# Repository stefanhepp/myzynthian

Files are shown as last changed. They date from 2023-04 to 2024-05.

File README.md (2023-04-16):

README
------

This project is a Zynthian case build with the following features:

- The hardware is based on:
    - Raspberry Pi 3/4 with passive cooler
    - IQaudio DAC+ audio shield
    - 7" LCD DSI Touchscreen
- Custom IO expander board for MIDI, 4x encoders

Sources
-------

The IO Expander board design is based on Zynthian's Zynaptic v3 design:
https://github.com/zynthian/zynthian-hw

The FreeCAD design uses the following models:
- 7" Display Reference Model: From Printables User Clough42: 
  https://www.printables.com/model/202234-official-raspberry-pi-7-touch-screen-reference-mod
- Raspberry PI 4: From GrabCAD User Zahid Salman: https://grabcad.com/library/raspberry-pi-model-3-4-cooling-1
- HifiBerry: From GrabCAD User Alain Gourvès: https://grabcad.com/library/hifiberry-dac-1
- Rotary Encoder: From GrabCAD User joel bennett: https://grabcad.com/library/rotary-encoder-ky-040-2
- DIN 5F Socket: From GrabCAD User Leininger Stéphane: https://grabcad.com/library/din-5f-type-mab-1
- LED 3mm: From GrabCAD User John Walker: https://grabcad.com/library/led-3mm-with-housing-1 

License
-------
Shield: [][cc-by-sa]

This work is licensed under a
[Creative Commons Attribution-ShareAlike 4.0 International License][cc-by-sa].

[][cc-by-sa]

[cc-by-sa]: http://creativecommons.org/licenses/by-sa/4.0/
[cc-by-sa-image]: https://licensebuttons.net/l/by-sa/4.0/88x31.png
[cc-by-sa-shield]: https://img.shields.io/badge/License-CC%20BY--SA%204.0-lightgrey.svg

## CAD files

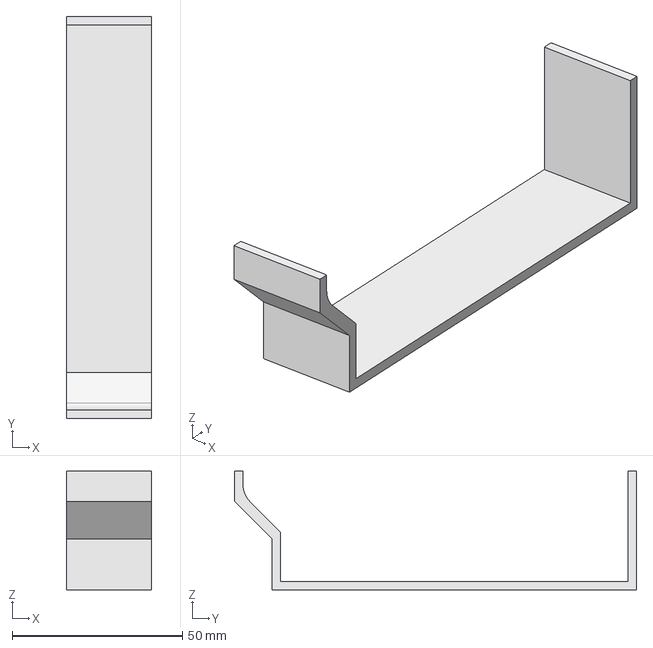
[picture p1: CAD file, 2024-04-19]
case/MyZynthian-Boutique-AssemblyHelper.step
25.0 x 118.0 x 34.9 mm

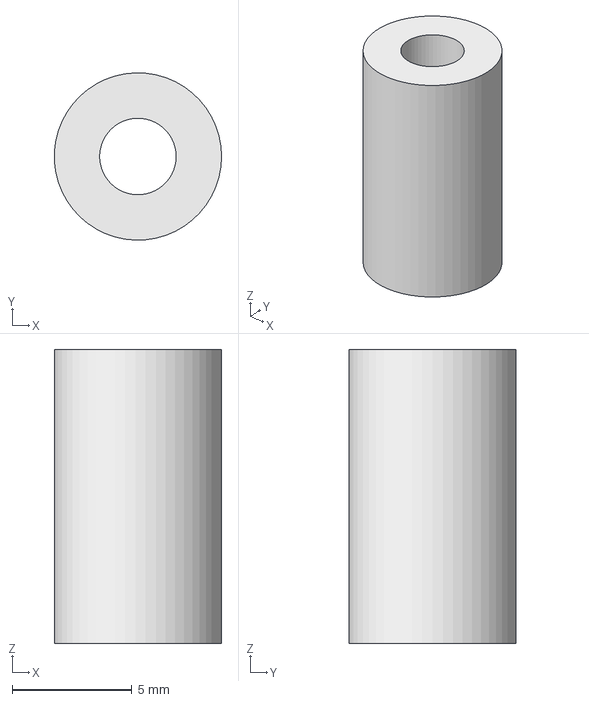
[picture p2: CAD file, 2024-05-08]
case/PCB-Spacer.FCStd
6.99 x 7.00 x 12.3 mm

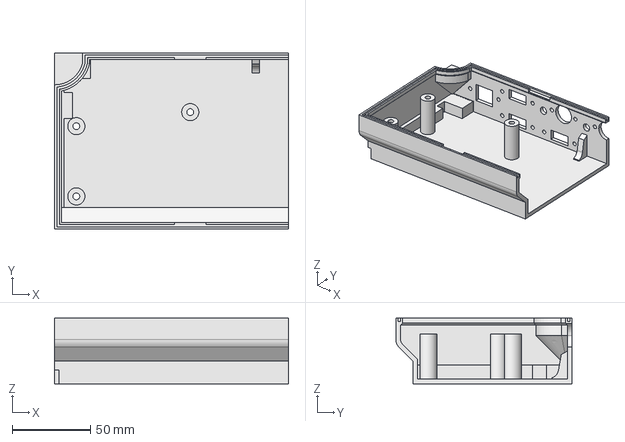
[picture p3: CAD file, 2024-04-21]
case/MyZynthian-Boutique-BottomLeft Body.step
150.0 x 113.0 x 42.0 mm

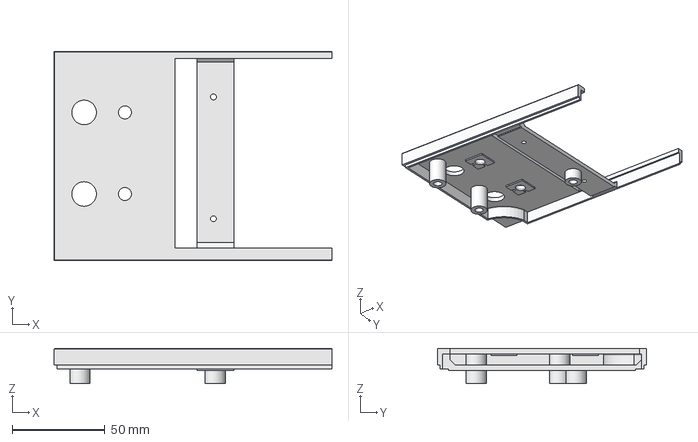
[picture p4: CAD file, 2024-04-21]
case/MyZynthian-Boutique-TopLeft Cover Body.step
149.9 x 113.0 x 19.0 mm

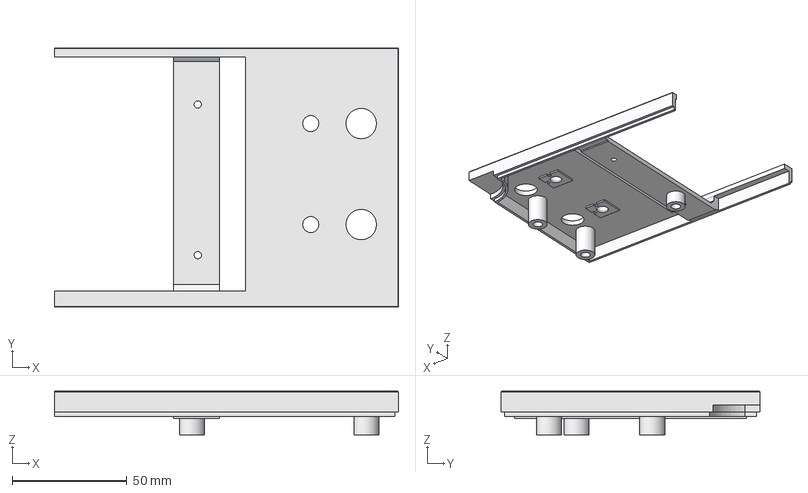
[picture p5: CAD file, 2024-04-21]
case/MyZynthian-Boutique-TopRight Cover Body.step
150.0 x 113.0 x 19.0 mm

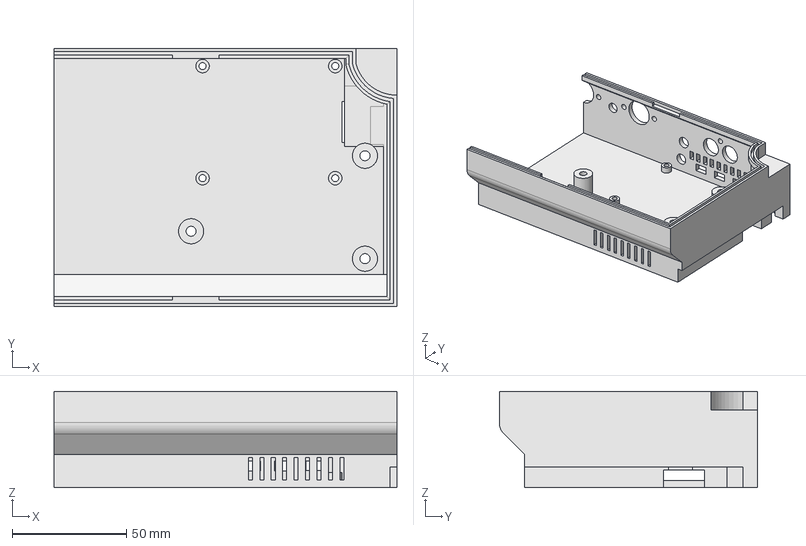
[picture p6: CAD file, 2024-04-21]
case/MyZynthian-Boutique-BottomRight Body.step
150.0 x 113.0 x 42.0 mm

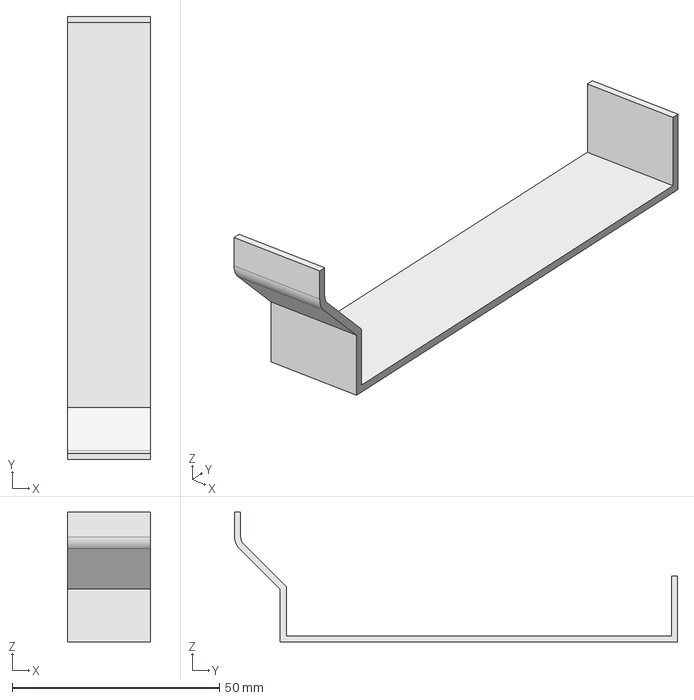
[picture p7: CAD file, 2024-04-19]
case/MyZynthian-Boutique-BodyConnector.step
20.0 x 107.0 x 31.4 mm

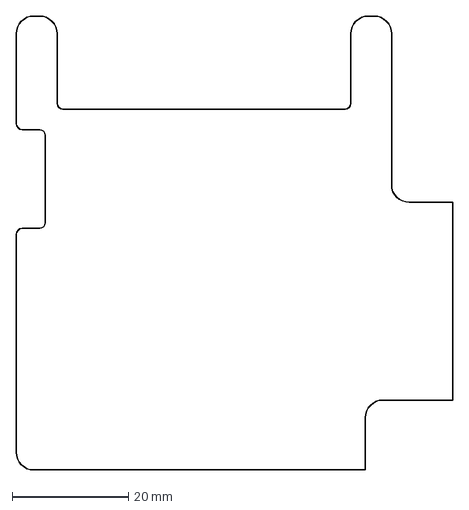
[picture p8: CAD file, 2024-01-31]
case/MyZynthian-Boutique-ZynthianIO Board Outline.dxf
75.0 x 78.0 mm

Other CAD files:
case/PCB-Spacer-Spacer.step

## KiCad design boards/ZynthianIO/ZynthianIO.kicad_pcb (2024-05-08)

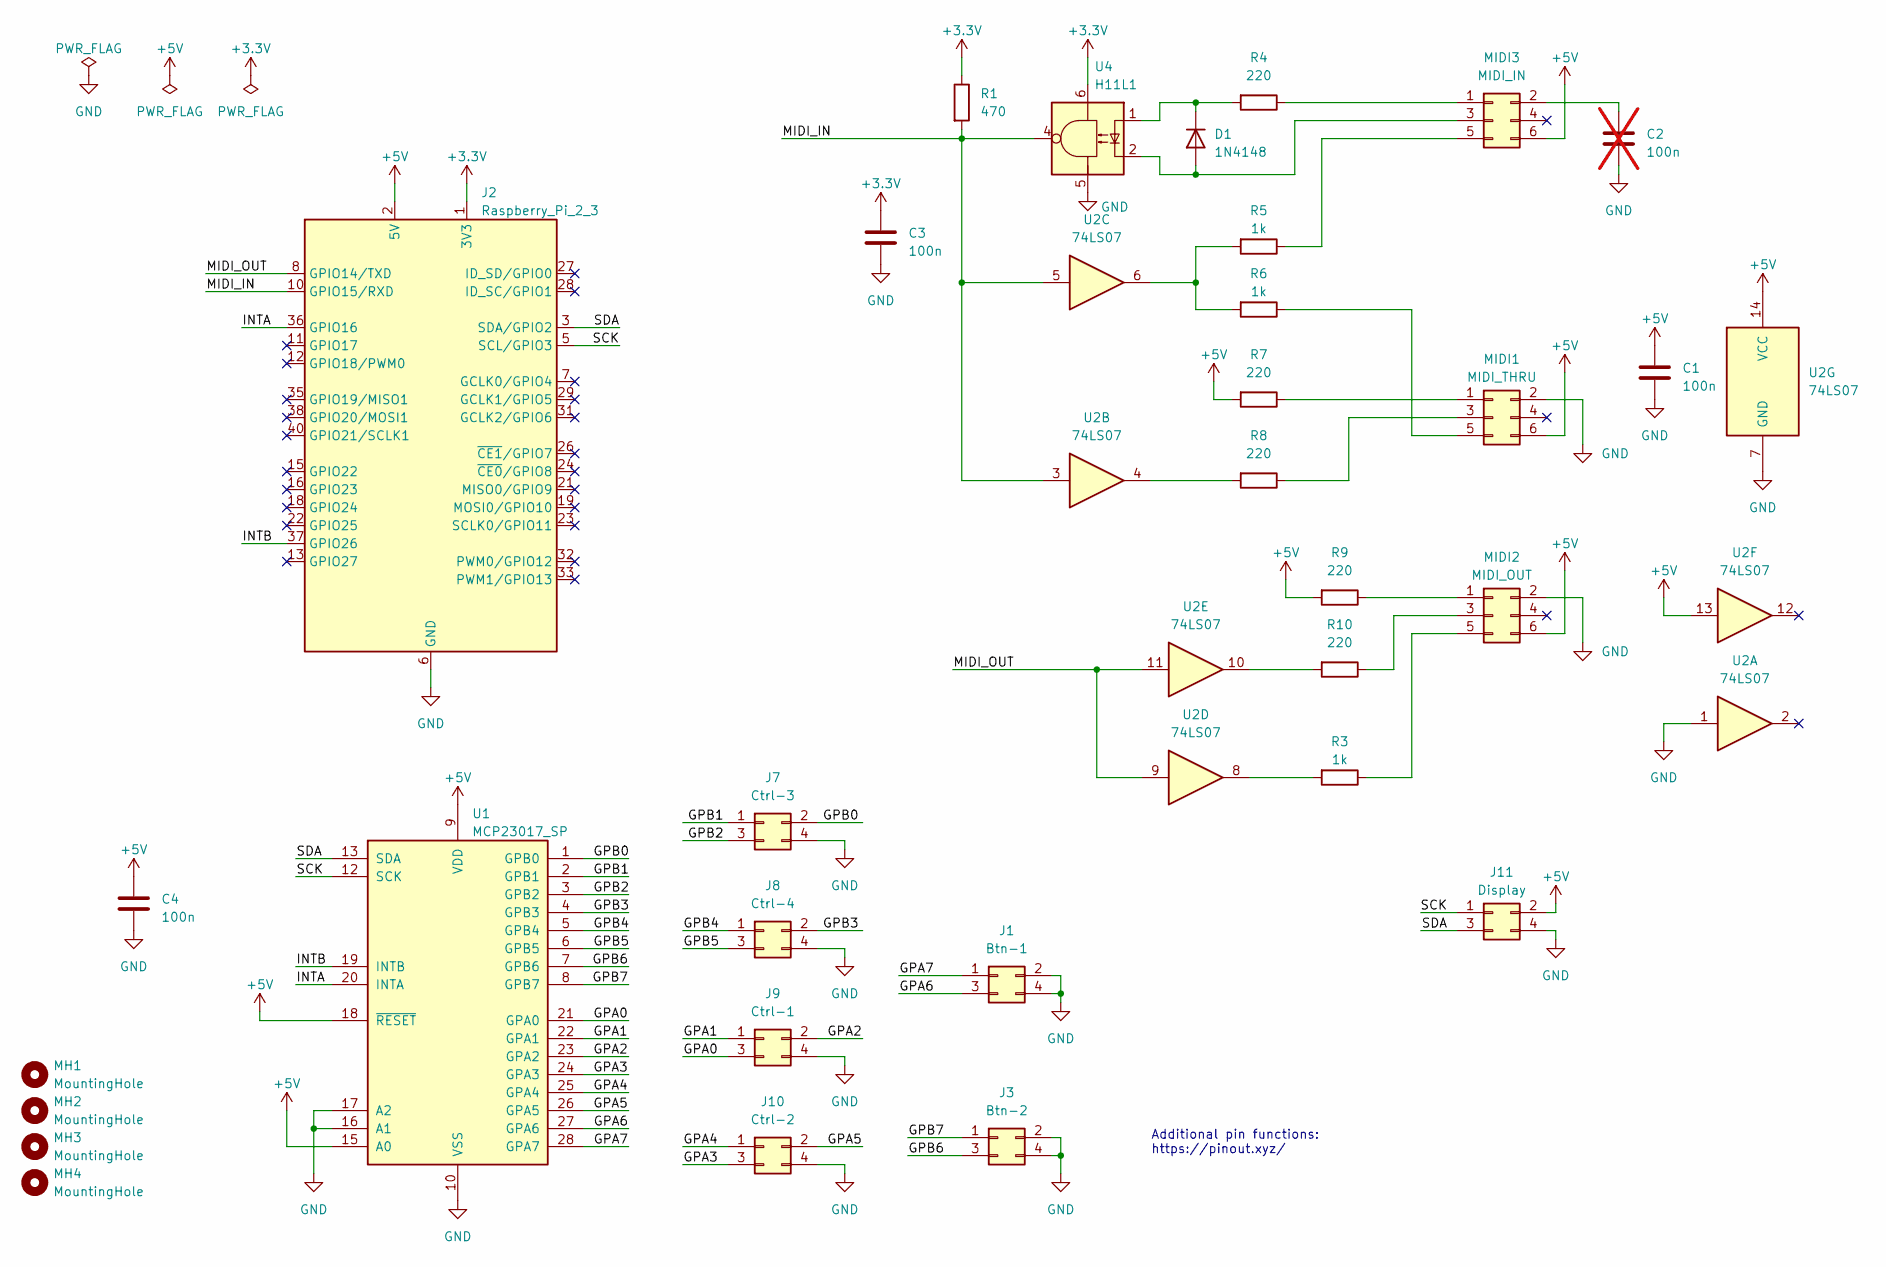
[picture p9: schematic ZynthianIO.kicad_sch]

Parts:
C1, C3, C4: 100n; C_Disc_D5.0mm_W2.5mm_P5.00mm
C2: 100n; C_Disc_D5.0mm_W2.5mm_P5.00mm; not fitted
D1: 1N4148; D_DO-35_SOD27_P7.62mm_Horizontal
J1: Btn-1; PinHeader_2x02_P2.54mm_Horizontal
J2: Raspberry_Pi_2_3; PinSocket_2x20_P2.54mm_Vertical
J3: Btn-2; PinHeader_2x02_P2.54mm_Horizontal
J7: Ctrl-3; PinHeader_2x02_P2.54mm_Horizontal
J8: Ctrl-4; PinHeader_2x02_P2.54mm_Horizontal
J9: Ctrl-1; PinHeader_2x02_P2.54mm_Horizontal
J10: Ctrl-2; PinHeader_2x02_P2.54mm_Horizontal
J11: Display; PinHeader_2x02_P2.54mm_Horizontal
MH1, MH2, MH3, MH4: MountingHole; MountingHole_2.7mm_M2.5
MIDI1: MIDI_THRU; PinHeader_2x03_P2.54mm_Horizontal
MIDI2: MIDI_OUT; PinHeader_2x03_P2.54mm_Horizontal
MIDI3: MIDI_IN; PinHeader_2x03_P2.54mm_Horizontal
R1: 470; R_Axial_DIN0207_L6.3mm_D2.5mm_P10.16mm_Horizontal
R3, R5, R6: 1k; R_Axial_DIN0207_L6.3mm_D2.5mm_P10.16mm_Horizontal
R4, R7, R8, R9, R10: 220; R_Axial_DIN0207_L6.3mm_D2.5mm_P10.16mm_Horizontal
U1: MCP23017_SP; DIP-28_W7.62mm
U2: 74LS07; DIP-14_W7.62mm
U4: H11L1; DIP-6_W7.62mm

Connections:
+3.3V: C3.1, J2.1 (3V3), J2.17 (3V3), R1.1, U4.6
+5V: C1.1, C4.1, J2.2 (5V), J2.4 (5V), J11.2, MIDI1.6, MIDI2.6, MIDI3.6, R7.2, R9.2, U1.9 (VDD), U1.15 (A0), U1.18 (~RESET), U2.13, U2.14 (VCC)
/GPA0: J9.3, U1.21 (GPA0)
/GPA1: J9.1, U1.22 (GPA1)
/GPA2: J9.2, U1.23 (GPA2)
/GPA3: J10.3, U1.24 (GPA3)
/GPA4: J10.1, U1.25 (GPA4)
/GPA5: J10.2, U1.26 (GPA5)
/GPA6: J1.3, U1.27 (GPA6)
/GPA7: J1.1, U1.28 (GPA7)
/GPB0: J7.2, U1.1 (GPB0)
/GPB1: J7.1, U1.2 (GPB1)
/GPB2: J7.3, U1.3 (GPB2)
/GPB3: J8.2, U1.4 (GPB3)
/GPB4: J8.1, U1.5 (GPB4)
/GPB5: J8.3, U1.6 (GPB5)
/GPB6: J3.3, U1.7 (GPB6)
/GPB7: J3.1, U1.8 (GPB7)
/INTA: J2.36 (GPIO16), U1.20 (INTA)
/INTB: J2.37 (GPIO26), U1.19 (INTB)
/MIDI_IN: J2.10 (GPIO15/RXD), R1.2, U2.3, U2.5, U4.4
/MIDI_OUT: J2.8 (GPIO14/TXD), U2.9, U2.11
/SCK: J2.5 (SCL/GPIO3), J11.1, U1.12 (SCK)
/SDA: J2.3 (SDA/GPIO2), J11.3, U1.13 (SDA)
GND: C1.2, C2.2, C3.2, C4.2, J1.2, J1.4, J2.6 (GND), J2.9 (GND), J2.14 (GND), J2.20 (GND), J2.25 (GND), J2.30 (GND), J2.34 (GND), J2.39 (GND), J3.2, J3.4, J7.4, J8.4, J9.4, J10.4, J11.4, MIDI1.2, MIDI2.2, U1.10 (VSS), U1.16 (A1), U1.17 (A2), U2.1, U2.7 (GND), U4.5
unnamed: D1.2 (A), MIDI3.3, U4.2
unnamed: D1.1 (K), R4.2, U4.1
unnamed: MIDI1.1, R7.1
unnamed: MIDI1.3, R8.1
unnamed: MIDI1.5, R6.1
unnamed: MIDI2.1, R9.1
unnamed: MIDI2.3, R10.1
unnamed: MIDI2.5, R3.1
unnamed: MIDI3.1, R4.1
unnamed: C2.1, MIDI3.2
unnamed: MIDI3.5, R5.1
unnamed: R3.2, U2.8
unnamed: R5.2, R6.2, U2.6
unnamed: R8.2, U2.4
unnamed: R10.2, U2.10

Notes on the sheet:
Additional pin functions: https://pinout.xyz/

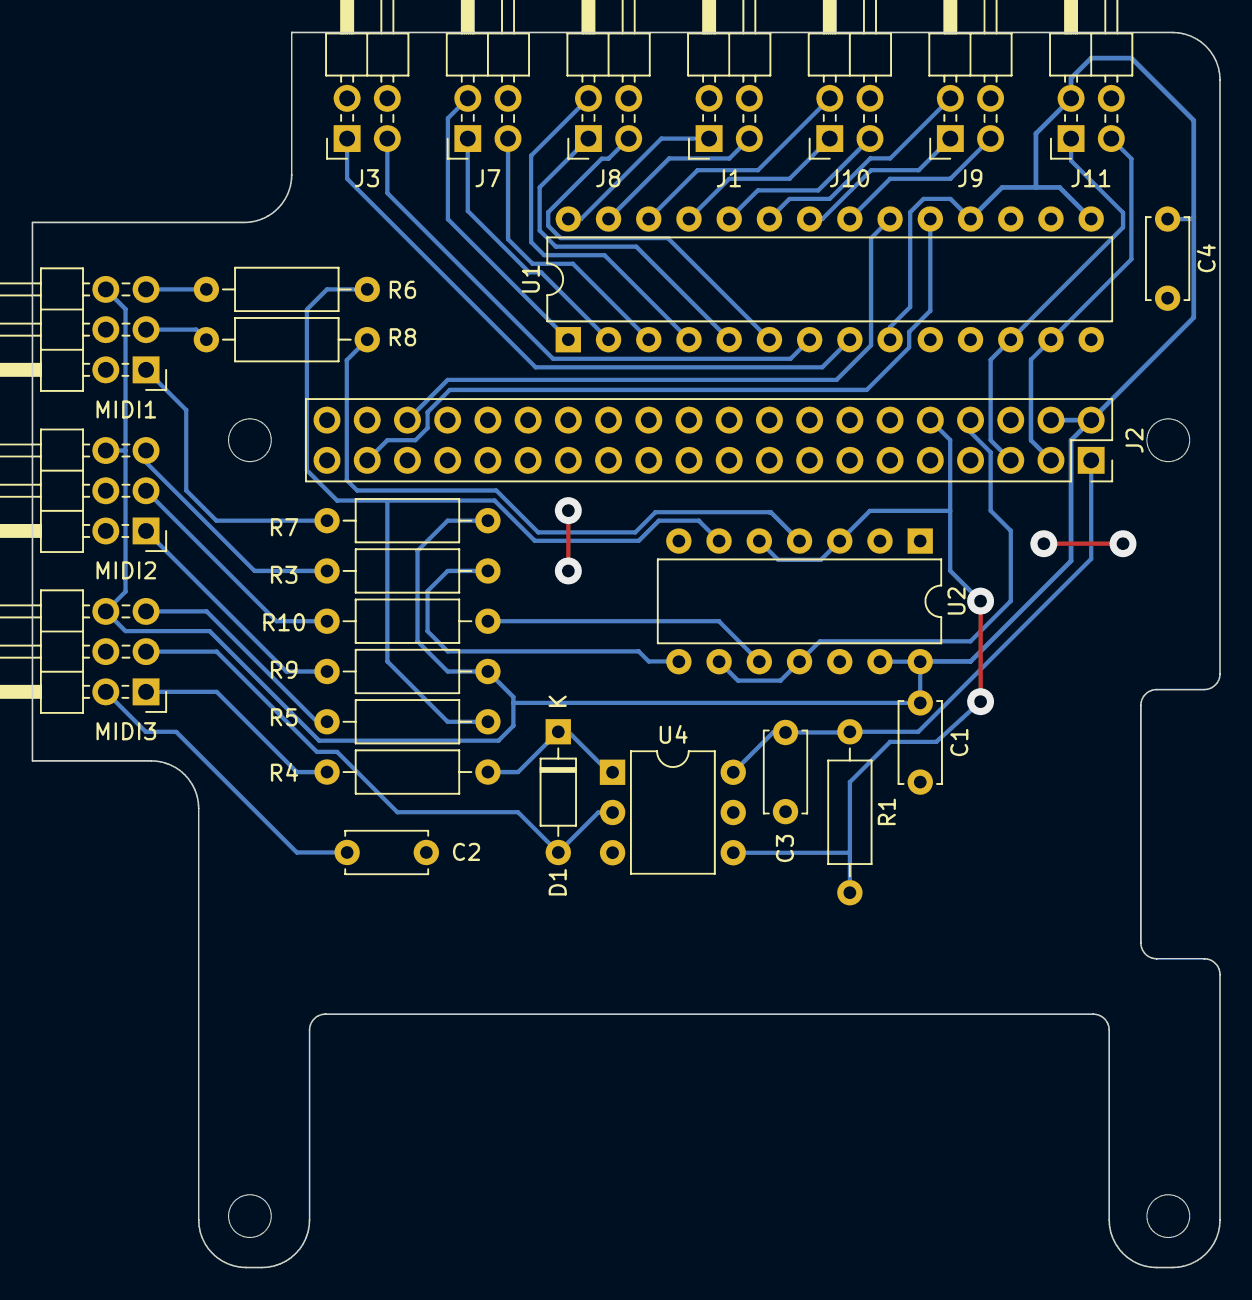
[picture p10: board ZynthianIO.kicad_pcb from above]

Board: 2 copper layers, 75.0 x 78.0 mm, 32 parts (0 on the bottom side), 40 nets.

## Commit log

2023-04-16 First IO expander board design, including PCB
    [Connectors.kicad_pcb, Connectors.kicad_sch, ZynthianIO.kicad_pcb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]
2023-04-16 Added IO Expander 3D model and connectors to case design, added references to sources.
    [ZynthianIO.kicad_sch]
2023-04-16 Added LED for MIDI connectors
2023-04-17 Removed temporary and local KiCAD files
    [ZynthianIO.kicad_pcb]
2023-04-18 Updated IO expander board with Raspberry HAT template PCB design
    [ZynthianIO.kicad_pcb, ZynthianIO.kicad_sch]
2023-04-18 Fixing several layout issues due to KiCAD 7.0.2/Linux update
    [ZynthianIO.kicad_pcb, ZynthianIO.kicad_sch]
2023-04-18 Updated 3D case design with new IO expander PCB
2023-10-24 Some first drawings for Zynthian case
    [ZynthianIO.kicad_pcb]
2024-01-13 Added some cover design for Zynthian case design
2024-01-23 Initial new Boutique formfactor case design
2024-01-28 Fixed FreeCAD sketches, fixed display mounting position
2024-01-28 Added top cover screw posts
2024-01-28 Finished Boutique case design, added Step files
    [MyZynthian-Boutique-AssemblyHelper.step, MyZynthian-Boutique-BodyConnector.step, MyZynthian-Boutique-BottomLeft Body.step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]
2024-01-29 Fixed several cutout clearances, added additional airvents
    [MyZynthian-Boutique-BottomLeft Body.step, MyZynthian-Boutique-BottomRight Body.step, MyZynthian-Boutique-TopLeft Cover Body.step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]
2024-01-30 Fixed cinch connector cutout location
    [MyZynthian-Boutique-BottomLeft Body.step, MyZynthian-Boutique-BottomRight Body.step]
2024-01-31 New ZynthianIO board design for Boutique case
    [MyZynthian-Boutique-ZynthianIO Board Outline.dxf, ZynthianIO.kicad_pcb, ZynthianIO.kicad_sch]
2024-02-13 Fixed MIDI interfaces
    [Connectors.kicad_sch, ZynthianIO.kicad_pcb, ZynthianIO.kicad_sch]
2024-03-03 Updated to KiCAD 8, use H11L1 as optocoupler
    [ZynthianIO.kicad_pcb, ZynthianIO.kicad_sch]
2024-03-13 Added PCB dimensions
    [ZynthianIO.kicad_pcb]
2024-03-14 Using 74LS07 OC buffer to avoid excessive LED currents
    [Connectors.kicad_sch, ZynthianIO.kicad_pcb, ZynthianIO.kicad_sch]
2024-04-19 Several fixes to reinfoce case
    [MyZynthian-Boutique-AssemblyHelper.step, MyZynthian-Boutique-BodyConnector.step, MyZynthian-Boutique-BottomLeft Body.step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]
2024-04-20 Fixed position of Raspberry Pi due to larger wall thickness
    [MyZynthian-Boutique-BottomLeft Body.step, MyZynthian-Boutique-BottomRight Body.step, MyZynthian-Boutique-TopLeft Cover Body.step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]
2024-04-21 Added chamfer to top cover
    [MyZynthian-Boutique-BottomLeft Body.step, MyZynthian-Boutique-BottomRight Body.step, MyZynthian-Boutique-TopLeft Cover Body.step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]
2024-04-25 Fixed resistor footprints and USB cutout locations
    [ZynthianIO.kicad_pcb, ZynthianIO.kicad_sch]
2024-04-25 Fixed footprint reference locations
    [ZynthianIO.kicad_pcb]
2024-05-01 Fixed resistor footprints, design rules update
    [ZynthianIO.kicad_pcb]
2024-05-05 Fixed locked ground plane
    [ZynthianIO.kicad_pcb]
2024-05-08 Added PCB spacer for IO board
    [PCB-Spacer-Spacer.step, PCB-Spacer.FCStd]
2024-05-08 Fixed ground plane connection, change 23017 address from 0x24 to 0x21
    [ZynthianIO.kicad_pcb, ZynthianIO.kicad_sch]
2024-05-12 Fixed rotary switches connections
    [Connectors.kicad_sch]
